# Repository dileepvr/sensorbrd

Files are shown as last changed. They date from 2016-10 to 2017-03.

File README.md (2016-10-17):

These are kicad schematics and design files for PCBs used in the EMS
weather-balloon external sensor board project. These design files are
being released (as of this writing on the 30th of April, 2016) under
the CERN Open Hardware License v1.2 (see file LICENSE.txt for text of
the license).  All future versions of the CERN Open Hardware License
automatically apply.

For more information about the Nearspace balloon project, visit: https://eugenemakerspace.com/wiki/Sites/NearSpaceBalloon

The PCB uses an ATMEGA32u4 microcontroller to gather information from
various sensor modules, including a weather monitoring chip, and
several photodiodes with varying wavelength-range sensitivities that
together approximate a poor man's low-resolution spectrometer. The PCB
footprints for most modules are designed to match breakout boards
available from Adafruit Industries (see BOM file for details).

- Dileep V. Reddy

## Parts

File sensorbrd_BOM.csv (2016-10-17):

Id | Designator | Package | Quantity | Designation | Supplier and ref
1 | R4,R2 | SM1206 | 2 | 4.7K | http://www.mouser.com/ProductDetail/ROHM-Semiconductor/ESR18EZPJ472/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
2 | C1,C2 | SM1206 | 2 | 22pF | http://www.mouser.com/ProductDetail/Kemet/C1206C220J5GACTU/
3 | C3 | SM1206 | 1 | 1uF | http://www.mouser.com/ProductDetail/AVX/12065C105K4Z2A/
4 | R1,R3,R6 | SM1206 | 3 | 10K | http://www.mouser.com/ProductDetail/ROHM-Semiconductor/ESR18EZPJ103/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
5 | R5 | SM1206 | 1 | 1K | http://www.mouser.com/ProductDetail/ROHM-Semiconductor/ESR18EZPJ102/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
6 | X1 | XTAL_6mmx3.5mm | 1 | XTAL 16MHz | http://www.mouser.com/ProductDetail/CTS/406C35E16M00000/
7 | CON2 | USB_MINI_B | 1 | USB-MINI-B | http://www.mouser.com/ProductDetail/SparkFun-Electronics/PRT-00587/
8 | U1 | TQFP44 | 1 | ATMEGA32U4-AU | http://www.mouser.com/ProductDetail/Atmel/ATMEGA32U4-AU/?qs=sGAEpiMZZMvqv2n3s2xjsYzXfq0AWv1C4u5a33SlKLw%3d
9 | SW1 | TACT_SW | 1 | MCU_RST | http://www.mouser.com/ProductDetail/TE-Connectivity-Alcoswitch/FSM4JSMA/
10 | K1 | PIN_ARRAY_3X1 | 1 | UV_SEN | https://www.adafruit.com/product/1918
11 | K2 | PIN_ARRAY_3X1 | 1 | ALS_PT19 | https://www.adafruit.com/product/2748
12 | P1 | PIN_ARRAY_2X1 | 1 | SOLAR_PV | https://solarbotics.com/product/scc2433b-mse/
13 | P3 | PIN_ARRAY-7X1 | 1 | TSL2561 | https://www.adafruit.com/product/439
14 | P2 | PIN_ARRAY-7X1 | 1 | BME280 | https://www.adafruit.com/product/2652
15 | CON1 | AVR_6_SMD | 1 | AVR-ISP-6-DR | http://www.mouser.com/ProductDetail/TE-Connectivity-AMP/1241050-3/

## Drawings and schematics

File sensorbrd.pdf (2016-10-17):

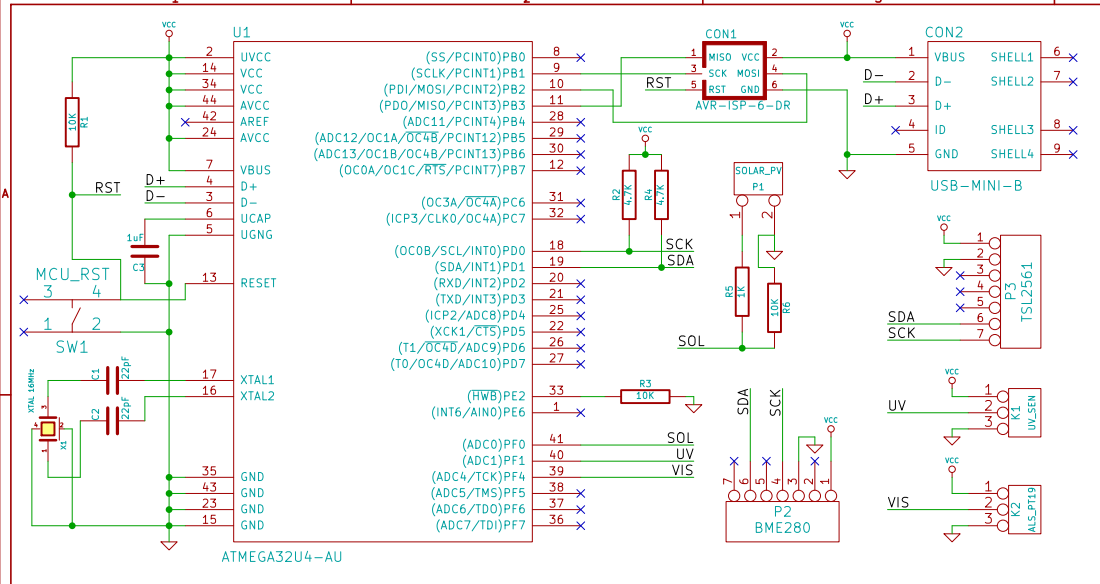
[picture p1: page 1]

Id: 1/1 Title: File: sensorbrd.sch Sheet: /

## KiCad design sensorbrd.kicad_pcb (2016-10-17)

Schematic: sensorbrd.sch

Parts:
C1, C2: 22pF
C3: 1uF
CON1: AVR-ISP-6-DR; AVR-ISP-6
CON2: USB-MINI-B
K1: UV_SEN
K2: ALS_PT19
P1: SOLAR_PV
P2: BME280
P3: TSL2561
R1, R3, R6: 10K
R2, R4: 4.7K
R5: 1K
SW1: MCU_RST
U1: ATMEGA32U4-AU
X1: XTAL 16MHz

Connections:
/D+: CON2.3 (D+), U1.4
/D-: CON2.2 (D-), U1.3
/RST: CON1.5 (RST), R1.2, SW1.4, U1.13
/SCK: P2.4, P3.7, R2.1, U1.18
/SDA: P2.6, P3.6, R4.1, U1.19
/SOL: R5.1, R6.2, U1.41
/UV: K1.2 (PM), U1.40
/VIS: K2.2 (PM), U1.39
GND: C3.1, CON1.6 (GND), CON2.5 (GND), K1.3, K2.3, P1.2 (PM), P2.3, P3.2, R3.2, R6.1, SW1.2, U1.5, U1.15, U1.23, U1.35, U1.43, X1.2 (case), X1.4
unnamed: CON1.1 (MISO), U1.11
unnamed: CON1.4 (MOSI), U1.10
unnamed: P1.1, R5.2
unnamed: C1.1, X1.3
unnamed: C2.1, X1.1
unnamed: C2.2, U1.16
unnamed: CON1.3 (SCK), U1.9
unnamed: R3.1, U1.33
unnamed: C3.2, U1.6
unnamed: C1.2, U1.17
VCC: CON1.2 (VCC), CON2.1 (VBUS), K1.1, K2.1, P2.1, P3.1, R1.1, R2.2, R4.2, U1.2, U1.7, U1.14, U1.24, U1.34, U1.44

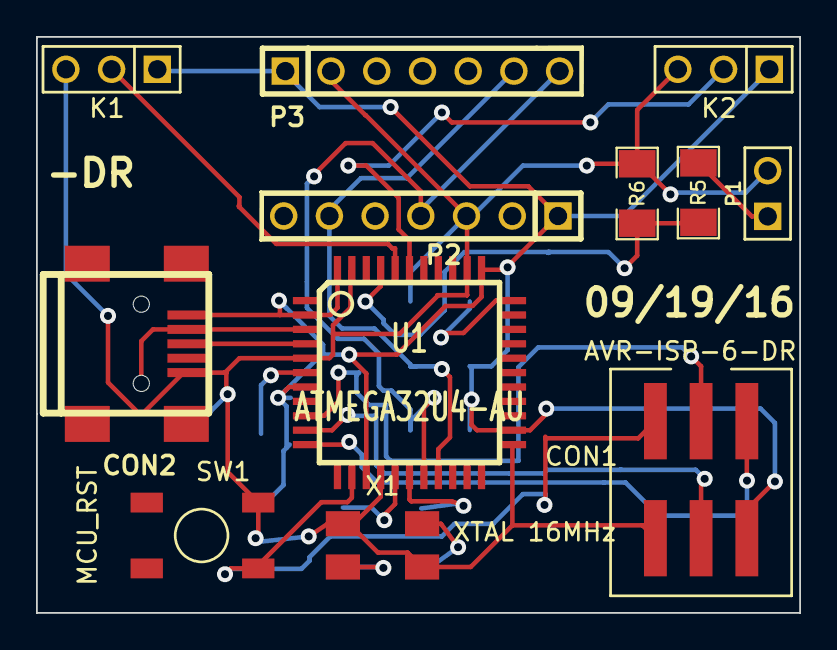
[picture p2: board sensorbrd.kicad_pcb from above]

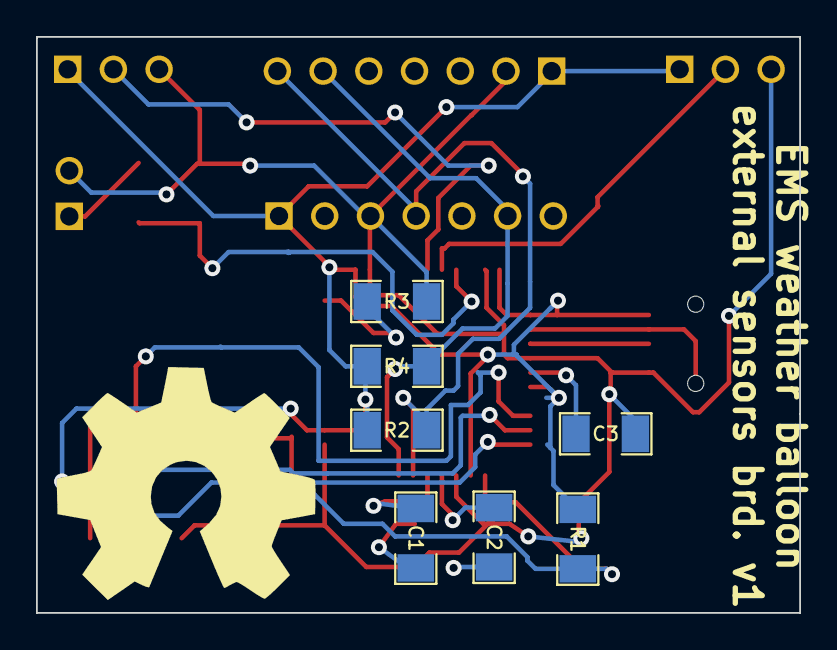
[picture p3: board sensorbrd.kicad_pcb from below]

Board: 2 copper layers, 42.4 x 32.0 mm, 19 parts (7 on the bottom side), 20 nets.

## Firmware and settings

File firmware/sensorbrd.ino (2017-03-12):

#include <Wire.h>
#include <Adafruit_Sensor.h>
#include <Adafruit_TSL2561_U.h>
#include <Adafruit_BME280.h>

Adafruit_TSL2561_Unified tsl = Adafruit_TSL2561_Unified(TSL2561_ADDR_FLOAT, 12345);


#define SEALEVELPRESSURE_HPA (1013.25)

Adafruit_BME280 bme; // I2C

uint16_t UV = 0;
uint16_t broadband = 0;
uint16_t visible = 0;
uint16_t infrared = 0;
uint16_t solarOCV = 0;

int UVin = A4;
int VISin = A3;
int PVin = A5;

/**************************************************************************/
/*
    Displays some basic information on this sensor from the unified
    sensor API sensor_t type (see Adafruit_Sensor for more information)
*/
/**************************************************************************/
void displaySensorDetails(void)
{
  sensor_t sensor;
  tsl.getSensor(&sensor);
  Serial.println("------------------------------------");
  Serial.print  ("Sensor:       "); Serial.println(sensor.name);
  Serial.print  ("Driver Ver:   "); Serial.println(sensor.version);
  Serial.print  ("Unique ID:    "); Serial.println(sensor.sensor_id);
  Serial.print  ("Max Value:    "); Serial.print(sensor.max_value); Serial.println(" lux");
  Serial.print  ("Min Value:    "); Serial.print(sensor.min_value); Serial.println(" lux");
  Serial.print  ("Resolution:   "); Serial.print(sensor.resolution); Serial.println(" lux");  
  Serial.println("------------------------------------");
  Serial.println("");
  delay(500);
}

/**************************************************************************/
/*
    Configures the gain and integration time for the TSL2561
*/
/**************************************************************************/
void configureSensor(void)
{
  /* You can also manually set the gain or enable auto-gain support */
  // tsl.setGain(TSL2561_GAIN_1X);      /* No gain ... use in bright light to avoid sensor saturation */
  // tsl.setGain(TSL2561_GAIN_16X);     /* 16x gain ... use in low light to boost sensitivity */
  tsl.enableAutoRange(true);            /* Auto-gain ... switches automatically between 1x and 16x */
  
  /* Changing the integration time gives you better sensor resolution (402ms = 16-bit data) */
  tsl.setIntegrationTime(TSL2561_INTEGRATIONTIME_13MS);      /* fast but low resolution */
  // tsl.setIntegrationTime(TSL2561_INTEGRATIONTIME_101MS);  /* medium resolution and speed   */
  // tsl.setIntegrationTime(TSL2561_INTEGRATIONTIME_402MS);  /* 16-bit data but slowest conversions */

  /* Update these values depending on what you've set above! */  
/*  Serial.println("------------------------------------");
  Serial.print  ("Gain:         "); Serial.println("Auto");
  Serial.print  ("Timing:       "); Serial.println("13 ms");
  Serial.println("------------------------------------");
  */
}

/**************************************************************************/
/*
    Arduino setup function (automatically called at startup)
*/
/**************************************************************************/
void setup(void) 
{
  Serial.begin(115200);
  Serial.println("Light Sensor Test"); Serial.println("");
  
  /* Initialise the sensor */
  if(!tsl.begin())
  {
    /* There was a problem detecting the ADXL345 ... check your connections */
    Serial.print("Ooops, no TSL2561 detected ... Check your wiring or I2C ADDR!");
    while(1);
  }

  if (!bme.begin()) {
    Serial.println("Could not find a valid BME280 sensor, check wiring!");
    while (1);
  }
  
  /* Display some basic information on this sensor */
//  displaySensorDetails();
  
  /* Setup the sensor gain and integration time */
  configureSensor();
  
  /* We're ready to go! */
 // Serial.println("");
}

/**************************************************************************/
/*
    Arduino loop function, called once 'setup' is complete (your own code
    should go here)
*/
/**************************************************************************/
void loop(void) 
{  
  /* Get a new sensor event */ 
  sensors_event_t event;
 

  UV = analogRead(UVin);
  visible = analogRead(VISin);
  solarOCV = analogRead(PVin);
      
  tsl.getEvent(&event);

 
  /* Display the results (light is measured in lux) */
  if (event.light)
  {
    tsl.getLuminosity(&broadband, &infrared);
    /*
    Serial.print(event.light); Serial.print(" lux");
    Serial.print(", Broadband: "); Serial.print(broadband); 
    Serial.print(", Infrared: "); Serial.print(infrared);
    */
    Serial.print("L:"); Serial.print(event.light); // luminosity in lux
    Serial.print(",B:"); Serial.print(broadband);
    Serial.print(",I:"); Serial.print(infrared);
  }
  else
  {
    /* If event.light = 0 lux the sensor is probably saturated
       and no reliable data could be generated! */
    Serial.println("Sensor overload");
  }
  /*
  Serial.print(", UV: "); Serial.print(UV);
  Serial.print(", Visible: "); Serial.print(visible); 
  Serial.print(", PV OCV: "); Serial.print(solarOCV);
  */
  Serial.print(",U:"); Serial.print(UV);
  Serial.print(",V:"); Serial.print(visible);
  Serial.print(",O:"); Serial.print(solarOCV);
  /*
  Serial.print(", T = "); Serial.print(bme.readTemperature()); Serial.print(" *C");
  Serial.print(", P = "); Serial.print(bme.readPressure() / 100.0F); Serial.print(" hPa");
  Serial.print(", H = "); Serial.print(bme.readHumidity()); Serial.println(" %");
  */
  Serial.print(",T:"); Serial.print(bme.readTemperature()); // degree Celcius
  Serial.print(",P:"); Serial.print(bme.readPressure()); // Pascals
  Serial.print(",H:"); Serial.println(bme.readHumidity()); // percentage
  
  delay(250); // 250 ms
}

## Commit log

2016-10-17 First commit after version 1.0 confirmed working.
    [sensorbrd-B_Cu.gbl, sensorbrd-B_Mask.gbs, sensorbrd-B_Paste.gbp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]
2017-03-12 Arduino firmware code added.
